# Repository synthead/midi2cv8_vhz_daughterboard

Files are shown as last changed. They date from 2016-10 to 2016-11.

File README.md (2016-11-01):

This is a KiCad project for a clone of PAiA's discontinued midi2cv8 V/Hz daughterboard.  It was designed from the same schematic as the original and is being shared with you under the kind permission of PAiA.  When installed, the board looks like this:



At the moment, there are [three bugs](https://github.com/synthead/midi2cv8_vhz_daughterboard/issues) in the circuit design.  I am only going to build one of these things, so it's unlikely that I'll fix them, so I figured that I would leave a note about it here.  These three bugs are solved by adding the wires below and bridging pin 8 of the 4051 to ground with a blob of solder.  The workarounds, when in-place, look like this:



In addition, if you're adding this V/Hz daughterboard to a midi2cv8 that is already configured for V/octave CV, you'll have to change resistor *R28 (a 5.6k ohm resistor should be there), and add a new resistor to #R32 on the midi2cv8 motherboard.  This wasn't obvious to me and spent a couple days trying to figure it out, so I thought I'd mention it here as well.  Here are the values from page 12 of the midi2cv8 manual:

|Designation|Value|Color Code A-B-C|
|---|---|---|
|\*R28|2700|red-violet-red|
|#R32|2700|red-violet-red|

Also, if this is the first time you're etching a board, I highly recommend tearing out a glossy page from a magazine and printing onto it for your toner transfer.  Also, don't bother with clothing irons.  I use an unmodified Swingline 1000L laminator.  Tape up the magazine paper so it doesn't slip around, then run it through the laminator a dozen times or so.  If you do it right, you'll end up with a transfer looking like this:



To get a head start, rendered PDFs for the PCB and the silk screen can be found in [the `rendered/` directory](https://github.com/synthead/midi2cv8_vhz_daughterboard/tree/master/rendered).  If you fancy it, you can transfer toner from the silkscreen PDF to the front of a single-layer PCB for a poor man's silkscreen.  It actually works really good and looks really nice!

Enjoy!

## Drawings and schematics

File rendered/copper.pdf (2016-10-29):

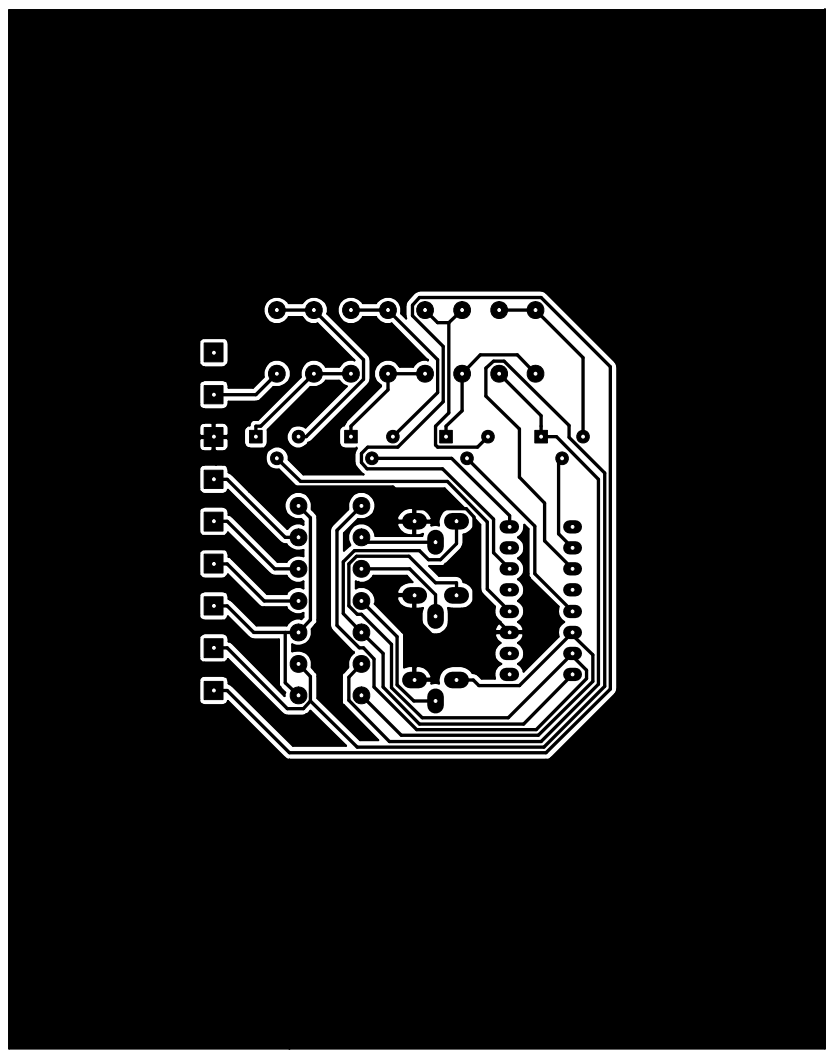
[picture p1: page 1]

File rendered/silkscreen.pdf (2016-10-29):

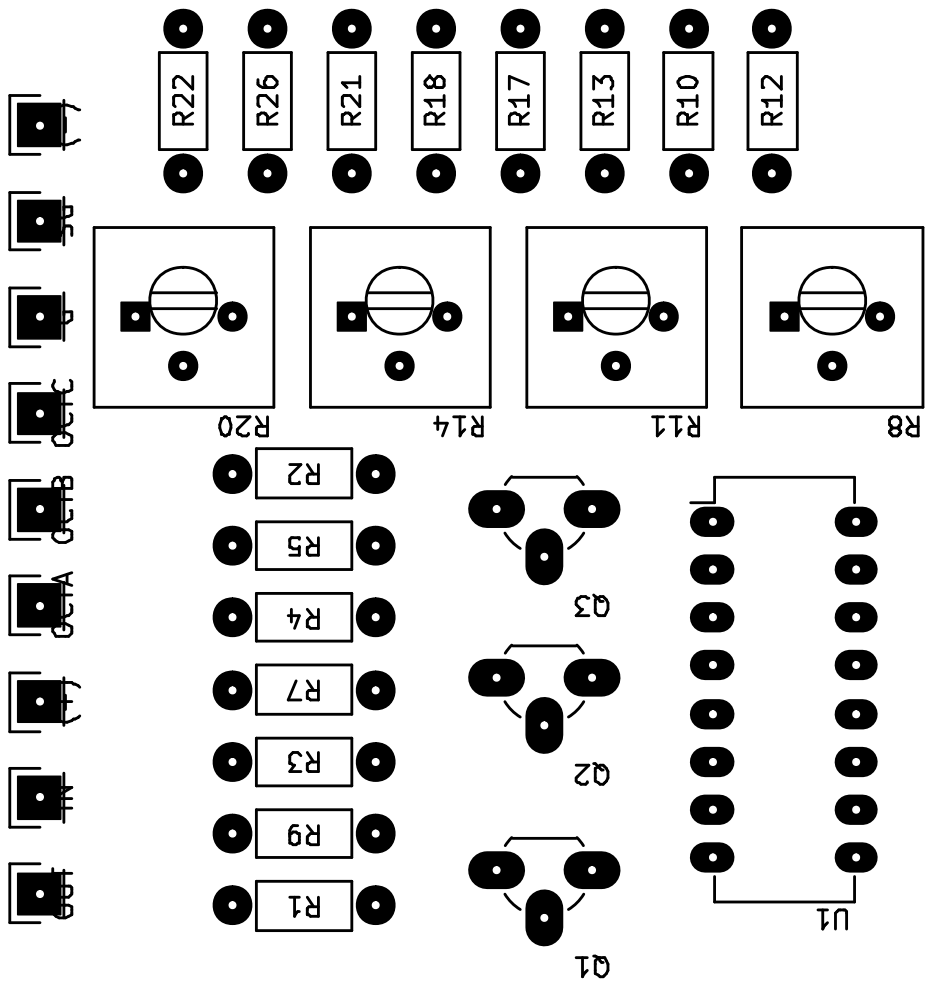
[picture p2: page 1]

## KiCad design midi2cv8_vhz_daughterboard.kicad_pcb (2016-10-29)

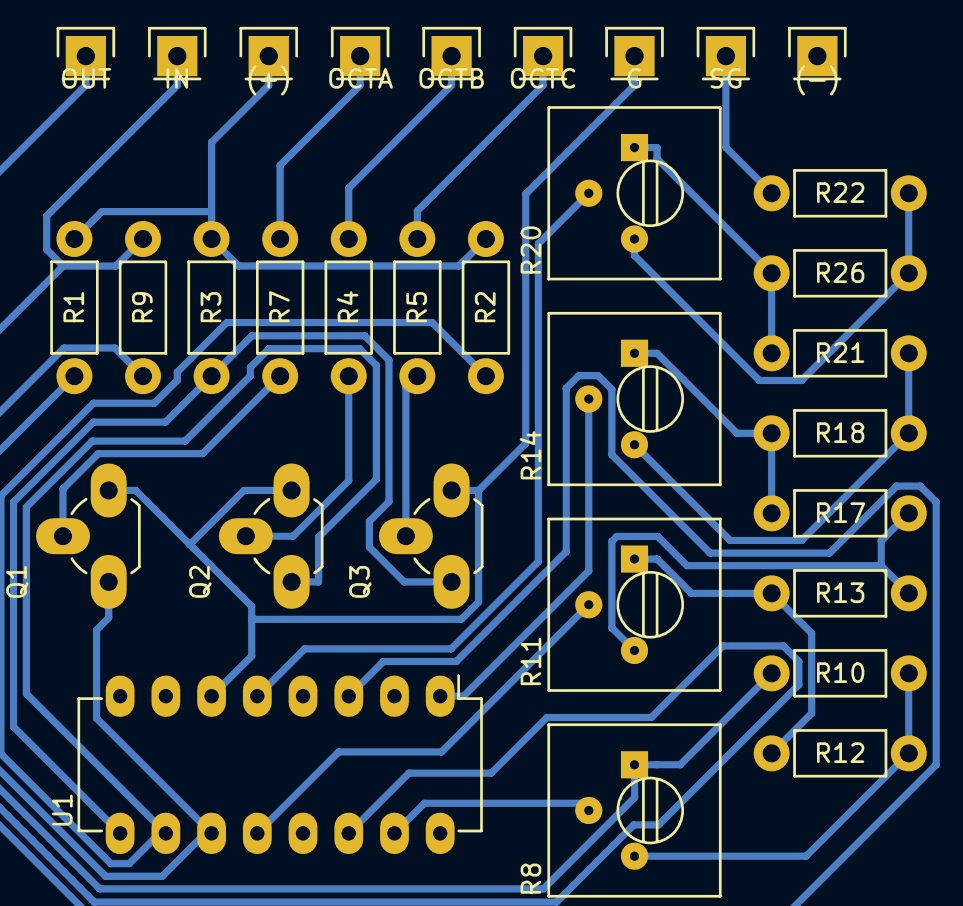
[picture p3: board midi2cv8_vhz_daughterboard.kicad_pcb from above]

Board: 2 copper layers, 32 parts (0 on the bottom side), 26 nets.

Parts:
(+): (+); Pin_Header_Straight_1x01
(-): (-); Pin_Header_Straight_1x01
G: G; Pin_Header_Straight_1x01
IN: IN; Pin_Header_Straight_1x01
OCTA: OCTA; Pin_Header_Straight_1x01
OCTB: OCTB; Pin_Header_Straight_1x01
OCTC: OCTC; Pin_Header_Straight_1x01
OUT: OUT; Pin_Header_Straight_1x01
Q1, Q2, Q3: NPN; TO-92_Rugged
R1, R2, R3, R4, R5, R7: 10k; Resistor_Horizontal_RM7mm
R8, R11, R14, R20: 1K; Potentiometer_Trimmer-Suntan-TSR-3386P
R9: 390; Resistor_Horizontal_RM7mm
R10: 270; Resistor_Horizontal_RM7mm
R12: 100; Resistor_Horizontal_RM7mm
R13: 120; Resistor_Horizontal_RM7mm
R17, R22: 47; Resistor_Horizontal_RM7mm
R18: 56; Resistor_Horizontal_RM7mm
R21, R26: 22; Resistor_Horizontal_RM7mm
SG: SG; Pin_Header_Straight_1x01
U1: 4051; DIP-16_W7.62mm_LongPads

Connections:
GNDREF: G.1, Q1.3, Q2.3, Q3.3, U1.6
unnamed: OUT.1, U1.3
unnamed: IN.1, R9.2, U1.14
unnamed: (+).1, R1.1, R2.1, R3.1
unnamed: OCTA.1, R7.2
unnamed: OCTB.1, R4.2
unnamed: OCTC.1, R5.2
unnamed: R22.1, SG.1
unnamed: Q1.1, R1.2, U1.11
unnamed: Q1.2, R7.1
unnamed: Q2.1, R2.2, U1.10
unnamed: Q2.2, R4.1
unnamed: Q3.1, R3.2, U1.9
unnamed: Q3.2, R5.1
unnamed: R8.2, U1.15
unnamed: R8.3, R10.1, R12.2
unnamed: R8.1, R9.1, R10.2
unnamed: R11.1, R12.1, R13.2
unnamed: R11.2, U1.12
unnamed: R11.3, R13.1, R17.2
unnamed: R14.1, R17.1, R18.2
unnamed: R14.2, U1.1
unnamed: R14.3, R18.1, R21.2
unnamed: R20.1, R21.1, R26.2
unnamed: R20.2, U1.5
unnamed: R20.3, R22.2, R26.1

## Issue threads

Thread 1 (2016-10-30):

4051 pin 7 needs to be connected to (-)

synthead, 2016-10-30:

synthead, 2016-10-30:
Workaround: add a wire from pin 7 to the (-) pad, like the white wire in this picture:
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

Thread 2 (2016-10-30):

4051 pin 8 needs to be connected to ground

synthead, 2016-10-30:

synthead, 2016-10-30:
Workaround: add a blob of solder to bridge the pin to the ground fill area like in this picture:
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

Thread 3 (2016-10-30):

4051 pin 16 (Vcc) needs to be connected to (+)

synthead, 2016-10-30:

synthead, 2016-10-30:
Workaround: add a wire to the back of the board from pin 16 to (+), which is the red wire in this picture:
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

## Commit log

2016-10-29 Initial commit.
    [midi2cv8_vhz_daughterboard.dsn, midi2cv8_vhz_daughterboard.kicad_pcb, midi2cv8_vhz_daughterboard.sch]
2016-11-01 Fix resistor table in README.md.
2016-11-01 Remove * from #R32 resistor code.
2016-11-01 Add a little more detail about the resistors to replace.
